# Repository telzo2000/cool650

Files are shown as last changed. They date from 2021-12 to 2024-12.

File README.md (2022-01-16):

# cool650

<br>

# Build Guide
https://github.com/telzo2000/cool650/blob/main/build_guide_for_cool650.md

## What is a cool650?

cool650 is macro pad keyboard,
<br>
and splite keyboard.
<br>
<br>
cool650は、cool635と同じ格子配列のキーボードです。
<br>
cool635は、m.kiが設計した、とてもコンパクトな30％キーボードです。
635とは、開発番号は６で、35キーのキーボードを指しています。
<br>

cool635 SU120で製作した試作版
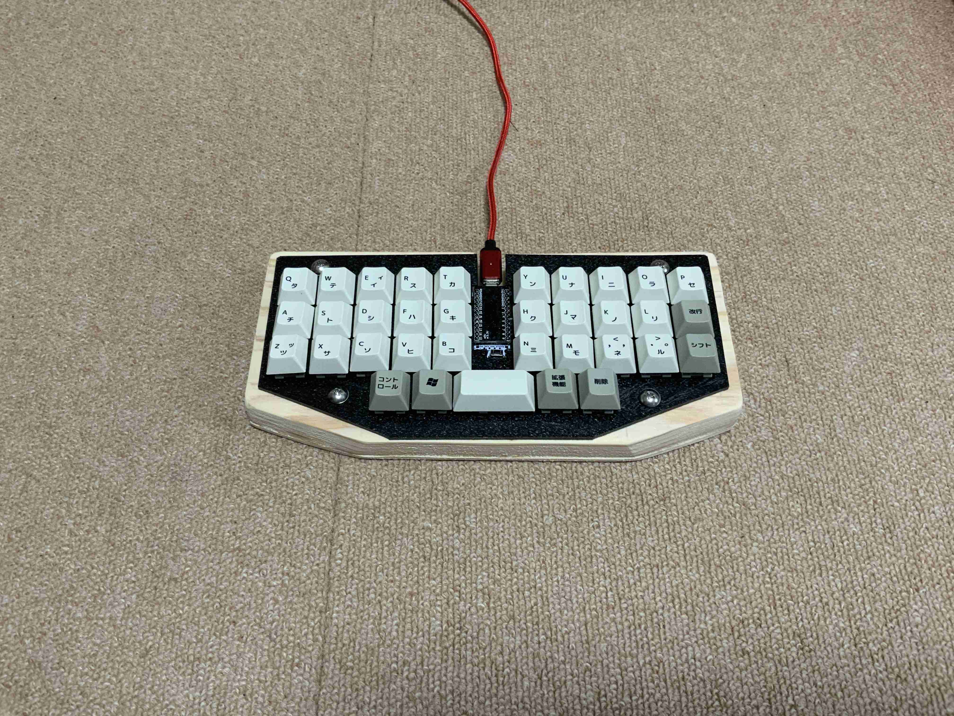
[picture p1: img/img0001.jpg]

分解したcool635
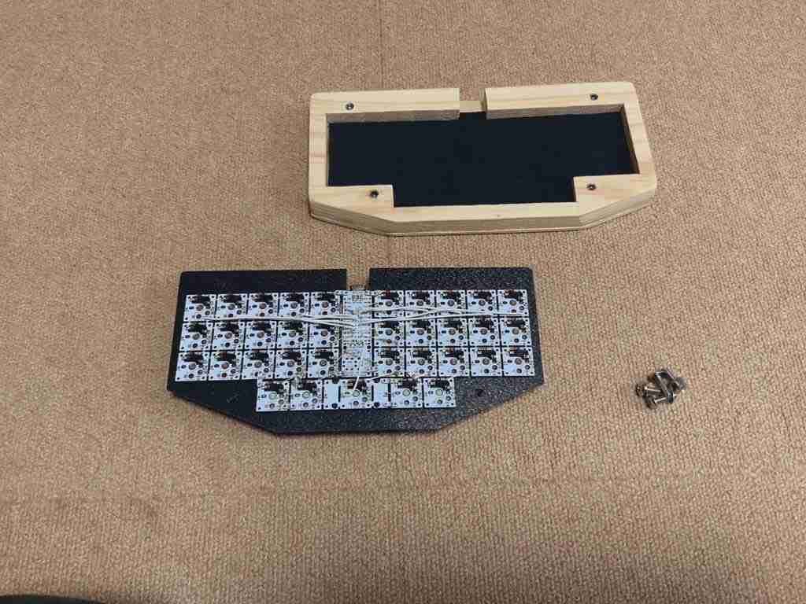
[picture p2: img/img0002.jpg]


cool635 kicadでPCBを設計した完成版
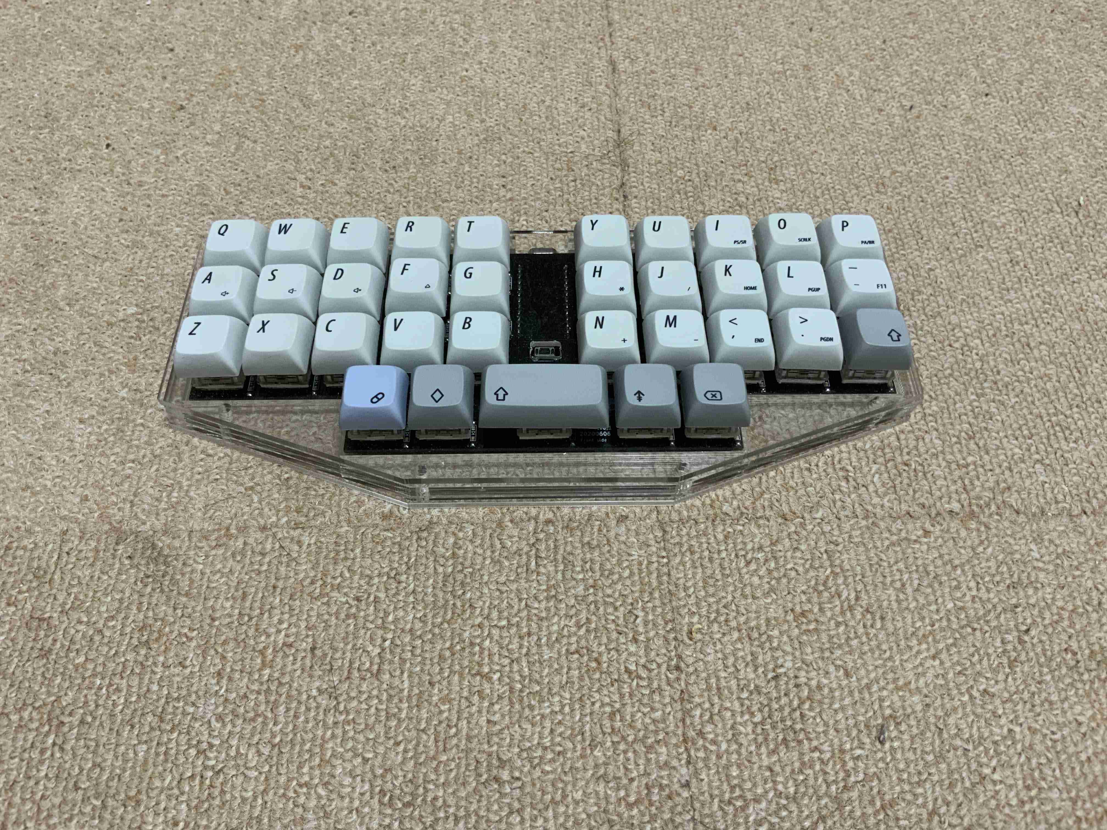
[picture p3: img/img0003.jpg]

裏側から見たcool635
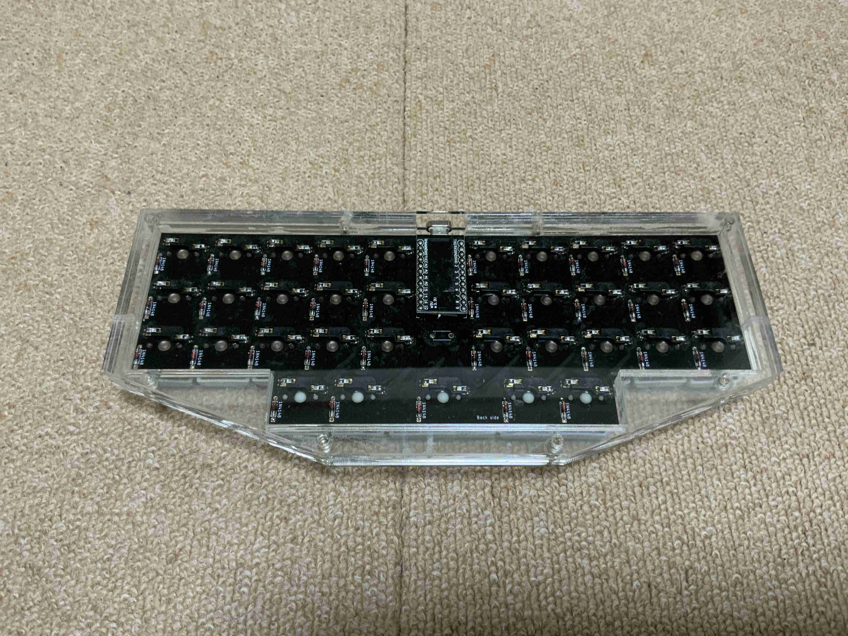
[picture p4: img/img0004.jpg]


cool635の完成版はアクリル積層ケースによって、埃などが侵入しにくいです。
<br>
しかし、m.kiは、ロウスタッガードのキーレイアウトが好みであったため、あまり使うことなく、お蔵入りしました。
<br>
<br>
cool650は、ALLPCBが100mmx150mm以下のPCB製作無料キャンペーンを利用して、設計しました。

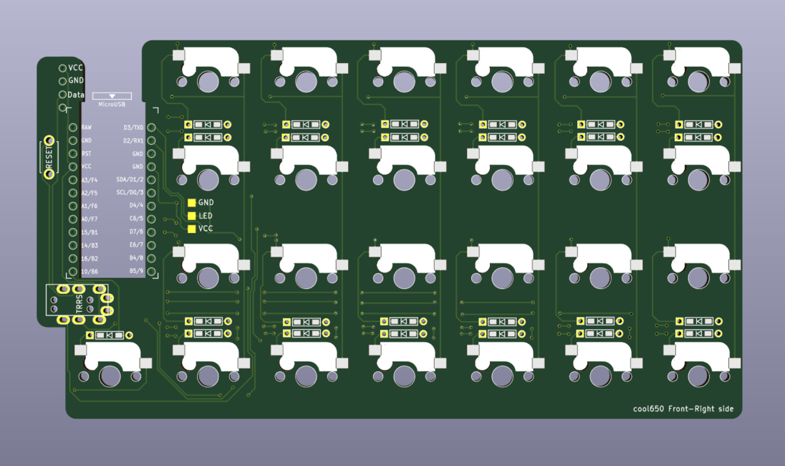
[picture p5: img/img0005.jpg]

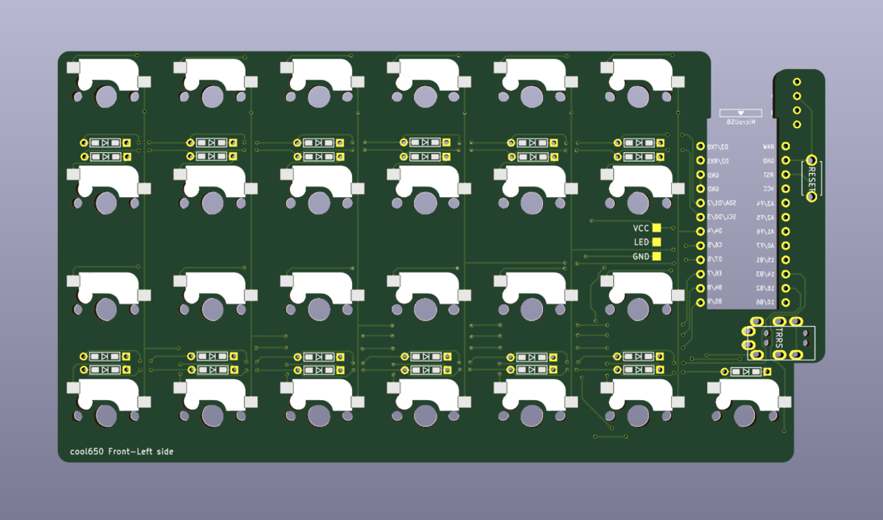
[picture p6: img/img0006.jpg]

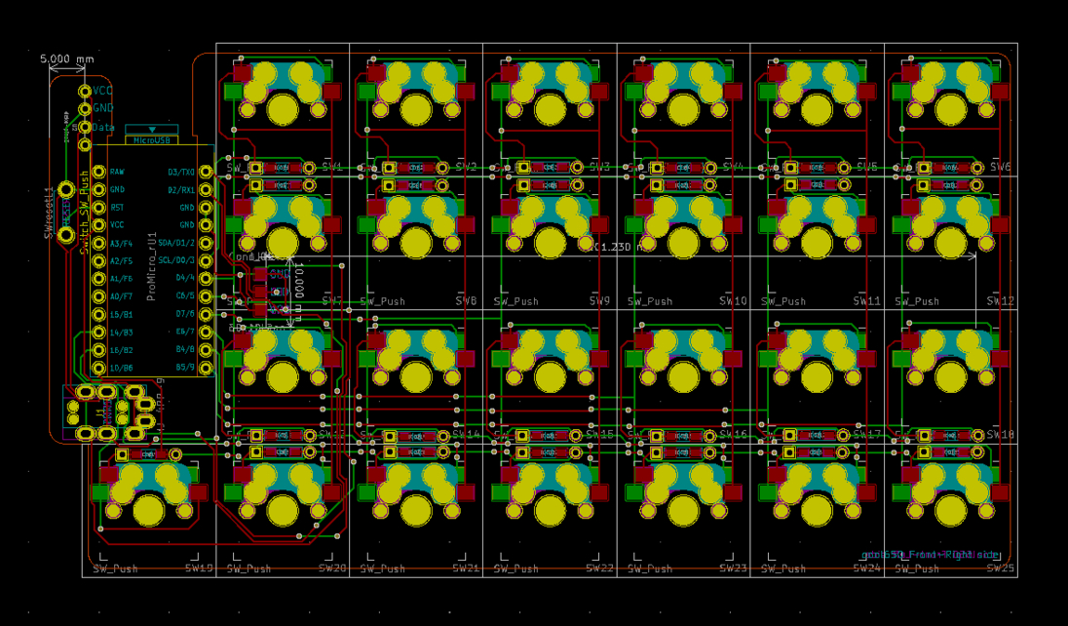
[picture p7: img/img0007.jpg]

ご覧の通り、表裏で使えるようになっています。一つで25キーあり、マクロパッドとして利用できます。二つをTRRSケーブルで繋ぐことにより、格子配列の分割キーボードとしても利用できます。
<br>
ケースはアクリル2mmを使用して、積層したものです。
配線関係の詳細は検討中ですが、60％のPoker互換のキーボードケースには、二つ分が収まります。
汎用ケースに収めることで50キーの格子配列のキーボード、取り出して、分割キーボード、単体で25キーのマクロパッドになることが、cool650のコンセプトです。

二つをケーブルで繋いだcool650

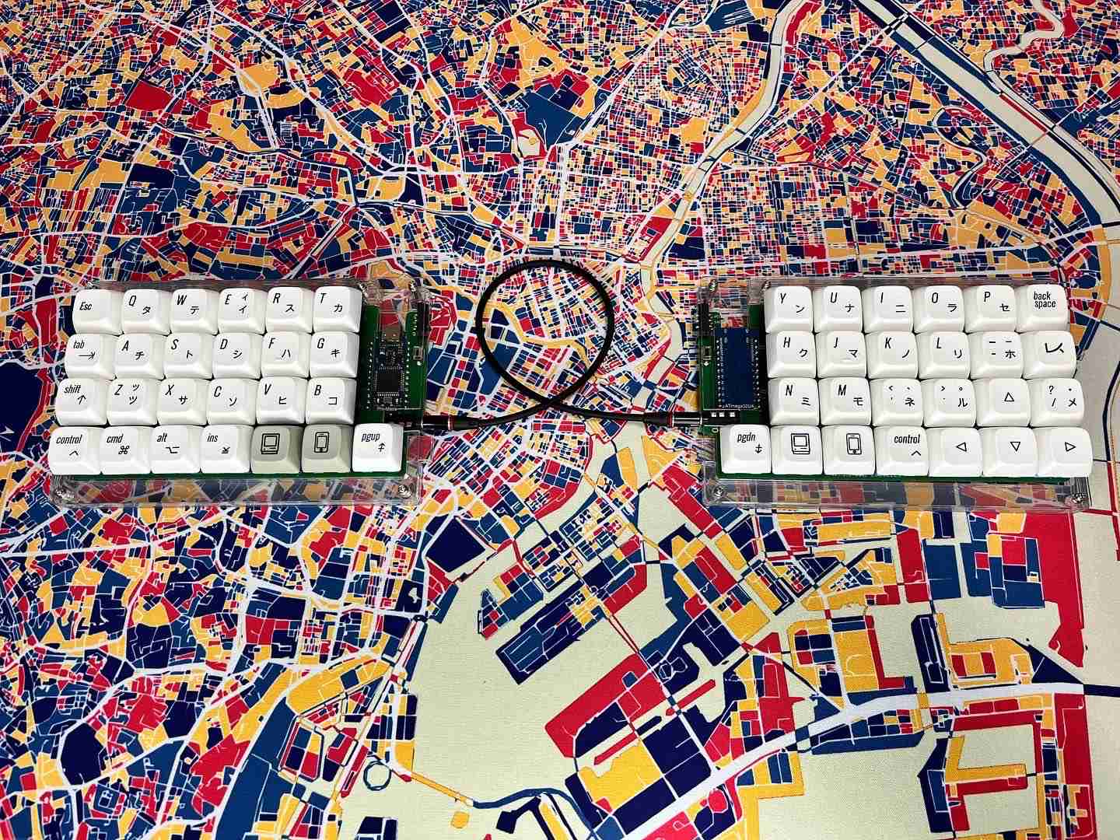
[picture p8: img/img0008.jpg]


60％のPoker互換のキーボードケースに収めたcool650　その１
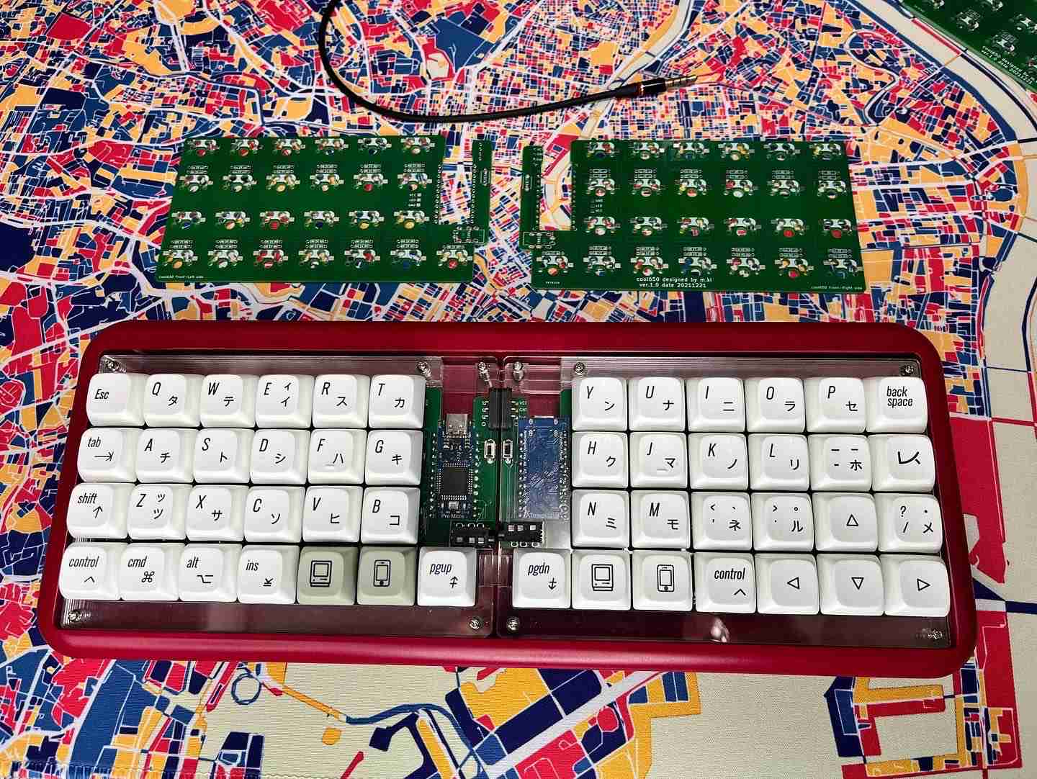
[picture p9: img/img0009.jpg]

60％のPoker互換のキーボードケースに収めたcool650　その２
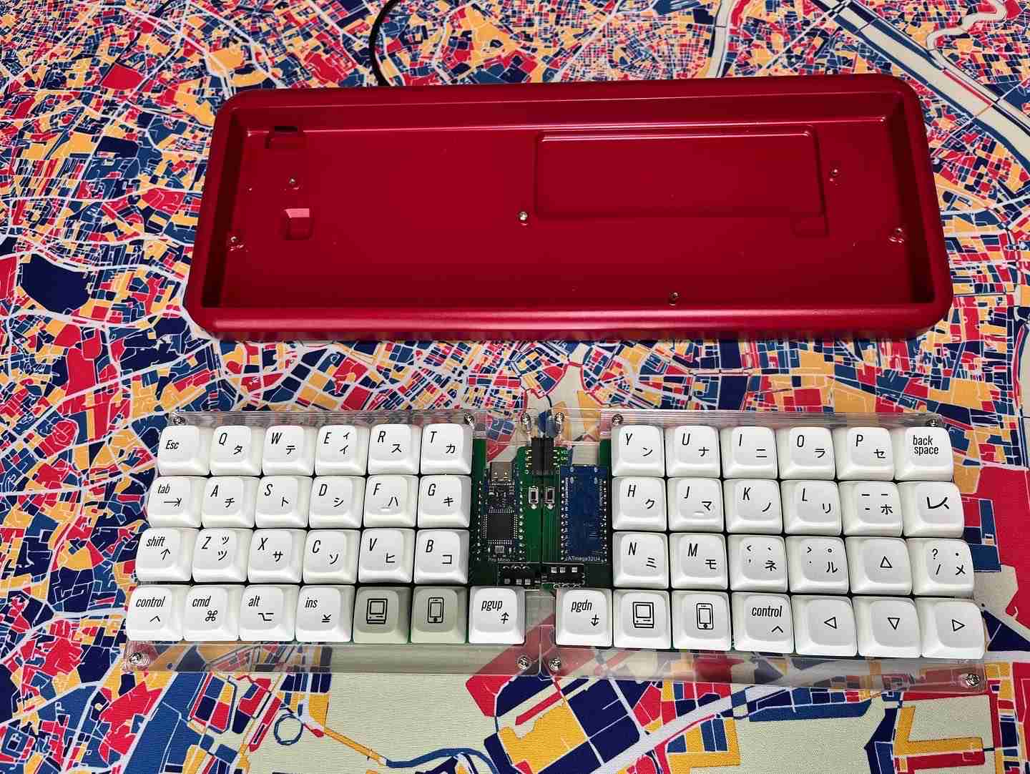
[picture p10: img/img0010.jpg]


最終的には、BBOX60ケースに収納することができました。
<br>
それ以外の60%POKER互換の汎用ケースに収納できる未確認です。
<br>
多分、できません。
<br>

## 令和４年１月６日　追記
<br>
kicad、ガーバー、アクリル積層ケースのデータを追加しました。
将来的には、有償で頒布するつもりですが、自分自身で作成したい方は、このデータをライセンスの範囲内で使用可能です。
<br>
本データを使用して発生した諸問題に対して、m.kiは補償等対応いたしません。
<br>
また、ファームウェアは用意しました。QMK Toolbox等でpro microに書き込んでください。
<br>
Remap等の必要なvia.hexは後日、用意します。
<br>
ファームウェア等の改変する際、下記の画像を参考にしてください。

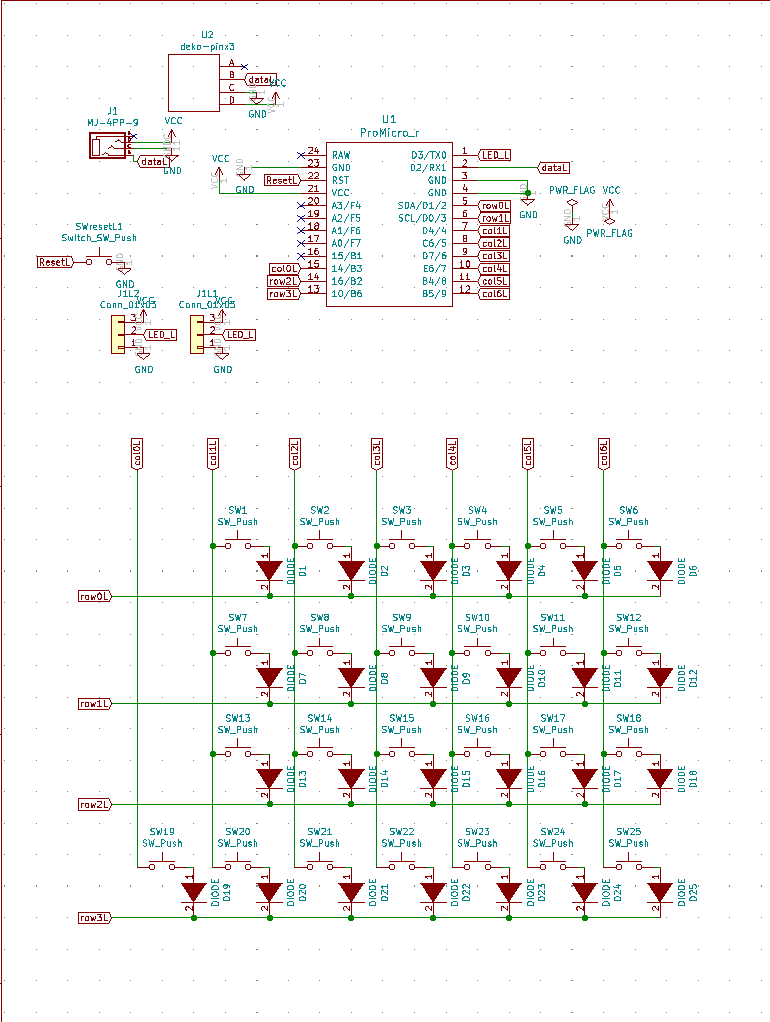
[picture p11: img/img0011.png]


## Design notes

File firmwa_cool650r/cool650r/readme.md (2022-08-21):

# cool650r

cool650r

*A short description of the keyboard/project*

* Keyboard Maintainer: [m.ki](https://github.com/telzo2000)
* Hardware Supported: *The PCBs, controllers supported*
* Hardware Availability: *Links to where you can find this hardware*

Make example for this keyboard (after setting up your build environment):

    make cool650r:default

Flashing example for this keyboard:

    make cool650r:default:flash

See the [build environment setup](https://docs.qmk.fm/#/getting_started_build_tools) and the [make instructions](https://docs.qmk.fm/#/getting_started_make_guide) for more information. Brand new to QMK? Start with our [Complete Newbs Guide](https://docs.qmk.fm/#/newbs).

## Bootloader

Enter the bootloader in 3 ways:

* **Bootmagic reset**: Hold down the key at (0,0) in the matrix (usually the top left key or Escape) and plug in the keyboard
* **Physical reset button**: Briefly press the button on the back of the PCB - some may have pads you must short instead
* **Keycode in layout**: Press the key mapped to `RESET` if it is available

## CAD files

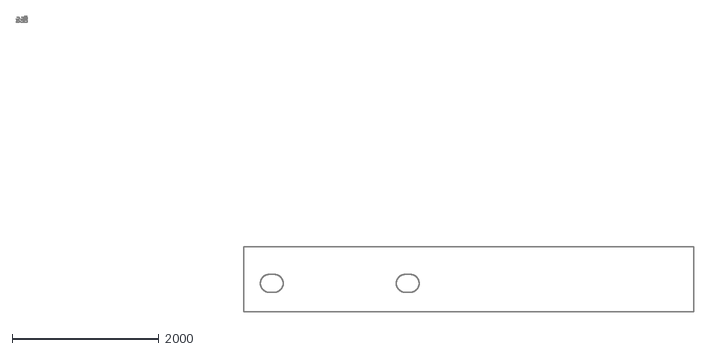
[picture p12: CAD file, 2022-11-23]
casedesign/case_wide/case_wide.dxf
9238.0 x 4030.2

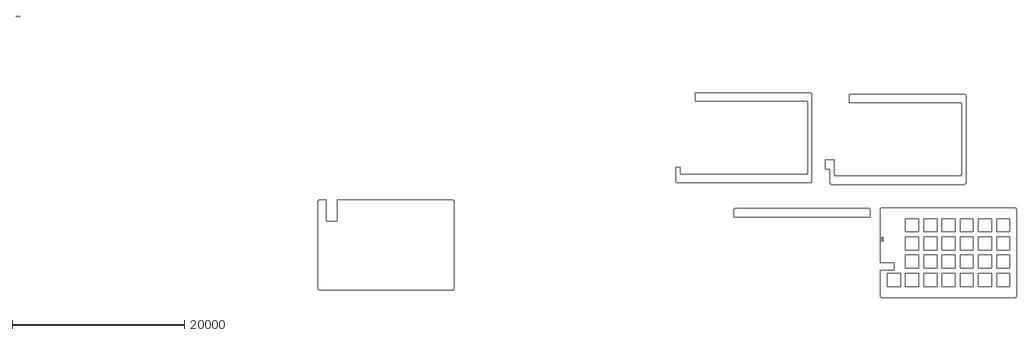
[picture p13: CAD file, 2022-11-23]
casedesign/cool650casedesign_new/cool650case.dxf
116101.8 x 32721.1

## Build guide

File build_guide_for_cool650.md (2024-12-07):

# Build Guide

## Parts list

|番号| 名前 | 数 | 備考 | 調達先の例 | 参考価格（送料込） |
|:-|:-|:-|--|--|--|
|1|PCB|1枚|macro pad|ALLPCB | ALLPCBの無料クーポンで５枚で０円<br>通常だと、26ドル|
||PCB|2枚|splite keyboard|ALLPCB|ALLPCBの無料クーポンで５枚で０円<br>通常だと、26ドル|
|2|M2ネジ|７本|６mm|DIYショップ等|10本程度で100円|
|3|M2ネジ|３本|８mm|DIYショップ等|10本程度で100円|
|4|M2スペーサー|PCB１枚につき５本|８mm|[ヒロスギネット](https://www.hirosugi-net.co.jp/shop/default.aspx)<br>[遊舎工房](https://shop.yushakobo.jp)等|20個で748円（税込）@ヒロスギネット|
|5|pro micro|PCB１枚につき１個|ピンヘッダが必要|[遊舎工房](https://shop.yushakobo.jp)<br>[TALP keyboard](https://talpkeyboard.net)|750円程度|
|6|スイッチプレート|１枚|アクリル|Elecrow|５枚で49.1ドル（送料込み）|
||ミドルプレート|４枚|アクリル|Elecrow|↑同じ|
||ボトムプレート|３枚（大１、小２）|アクリル|Elecrow|↑同じ|
|7|スイッチソケット|pcb１枚につき25個|MX|[遊舎工房](https://shop.yushakobo.jp)<br>[TALP keyboard](https://talpkeyboard.net)|10個で165円（税込）|
|8|ダイオード|pcb１枚につき25個|リードタイプ、SMDのどちらでも可|[遊舎工房](https://shop.yushakobo.jp)<br>[TALP keyboard](https://talpkeyboard.net)|100個で220円（税込）|
|9|リセットスイッチ|PCBにつき１個|タクタイルスイッチとも呼ばれる|[遊舎工房](https://shop.yushakobo.jp)<br>[TALP keyboard](https://talpkeyboard.net)|1個で11円（税込）|
|10|MXスイッチ|PCB１枚につき25個||[遊舎工房](https://shop.yushakobo.jp)<br>[TALP keyboard](https://talpkeyboard.net)等|1個で100円前後|
|11|キーキャップ|PCB１枚につき25個||[遊舎工房](https://shop.yushakobo.jp)<br>[TALP keyboard](https://talpkeyboard.net)|1個で100円前後<br>キーキャップセットで3000円程度から|
|12|ゴム足|PCB１枚につき４個|任意|DIYショップ等|100円程度|
|13|TRRSジャック|２本|splite keyboardとして使用する時|[遊舎工房](https://shop.yushakobo.jp)<br>[TALP keyboard](https://talpkeyboard.net)等|１個55円（税込）|
|14|TRRSケーブル|１本|splite keyboardとして使用する時|[遊舎工房](https://shop.yushakobo.jp)<br>[TALP keyboard](https://talpkeyboard.net)等|300円程度から|
|15|マグネット付きコネクタ|１組|合体して使うのであれば|[Ali Express](https://ja.aliexpress.com/item/1005003150326343.html?spm=a2g0o.9042311.0.0.399f4c4dbOjNiU)|400円程度|
|16|LED|２枚|任意<br>フルカラーシリアルLEDテープ 6個タイプ|[遊舎工房](https://shop.yushakobo.jp/collections/all-keyboard-parts/products/a01sl-00)|１枚550円|
|17|ロータリーエンコーダー|最大２個|任意<br>ver.1.1基板以降、<br>装着可能|[遊舎工房](https://shop.yushakobo.jp)<br>[TALP keyboard](https://talpkeyboard.net)等|400円程度から|

## 作り方

### 1　基板の向きを決める
PCB１枚を使用して、マクロパッドキーボードとして利用する場合は、pro micro設置部分が右側になるか、左側になるか、決定します。
<br>
PCBを２枚使用して、分割キーボードとして利用する場合は、左右それぞれの向きで作成してください。
<br>
<br>

### 2 ダイオードの取り付け
ダイオードをハンダ付けします。
<br>
全体で言えることですが、フラックスを使用してください。失敗を防げます。
<br>
写真ではリードタイプのダイオードのハンダ付けをしています。
<br>
SMDタイプのダイオードも使用できます。
<br>
ダイオードの向きに注意してください。
ダイオードはPCBの下面に取り付けるようにしてください。
<br>
<br>

### 3 スイッチソケットの取り付け
スイッチソケットのハンダ付けをします。
最初にPCBの片側のパッドに、予備ハンダをします。
<br>
次にスイッチソケットを乗せます。
<br>
ハンダゴテで、予備ハンダをした部分を温めて、ハンダ付けをします。
<br>
反対側のパッドとスイッチソケットの間にハンダを流し込むようにハンダ付けをします。
<br>
スイッチソケットの向きに注意してハンダ付けをしてください。
スイッチソケットはPCBの下面に取り付けるようにしてください。
<br>
<br>

### ◯オプション ロータリーエンコーダーの取り付け　
ver.1.1以降の基板では、左右のPCBの一番内側に、キースイッチの代わりに、ロータリーエンコーダーを取り付けることができます。
<br>
その場合、cool650rとなります。
<br>
<br>

### 4 リセットスイッチの取り付け
リセットスイッチ（タクタイルスイッチ）のハンダ付けをします。
リセットスイッチはPCBの上面に取り付けます。
<br>
リセットスイッチをマスキングテープ等で仮固定して、PCBの下面からハンダ付けをします。
<br>
<br>

### 5 TRRSジャックの取り付け
マクロパッドでは、取り付けなくても使用可能です。
<br>
分割キーボードで使用する場合は、左右それぞれぞの基板に１つずつ取り付けます。
<br>
TRRSジャックは、PCBの上面に取り付けます。
<br>
TRRSジャックをマスキングテープ等で仮固定して、PCBの下面からハンダ付けをします。
<br>
<br>

### 6  pro microの取り付け
pro microのハンダ付けをします。
本キーボードでは、薄さを求めるために、pro microをピンヘッダを使わずに、基板に直付けします。
<br>
ここでは、pro microのUSB端子や部品が付いている表面とします。
<br>
pro microの表面がPCB側に向くよう取り付けます。
pro microのUSB端子や部品がPCBに干渉しないよう、PCBの一部が切り抜かれています。
<br>
pro microの設置向きは、pro microの「RAW」の印字がPCBの外側にしてください。
<br>
<br>
＜ブレッドボードがある場合＞
<br>
取り付け方は次の手順になります。
<br>
①ブレッドボードにピンヘッダを挿して、pro microの表面をブレッドボード側に向けて、ピンヘッダを通します。
<br>
②pro microの裏面からハンダ付けをして、ピンヘッダを固定します。
<br>
③ブレッドボードからpro microを抜きます。
<br>
④ピンヘッダに付いているプラスチックをラジオペンチ等を用いて、外します。
<br>
⑤pro microの表面がPCB側に向くように、挿します。マスキングテープ等で仮固定します。
<br>
⑥pro microを挿したPCBの反対側からハンダ付けをします。長すぎるピンはニッパー等で切ってください。
<br>
<br>
＜ブレッドボードがない場合＞
<br>
取り付け方は次の手順になります。
<br>
①ピンヘッダをpro microの裏面から、pro micro、PCBの順で挿します。
マスキングテープで仮固定します。
<br>
②PCB側からピンヘッダをハンダ付けします。
<br>
③pro micro裏面のピンヘッダのプラスチックをラジオペンチ等を用いて、外します。
<br>
④pro microの裏面のハンダ付けをします。長すぎるピンはニッパー等で切ってください。
<br>
<br>

## 7 マグネット付きコネクタの取り付け
マクロパッドでは、取り付けなくても使用可能です。
<br>
分割キーボードで使用する場合は、左右それぞれぞの基板に１つずつ取り付けます。
<br>
マグネット付きコネクタがなくても、TRRSジャック、ケーブルがあれば、分割キーボードとして動作します。
<br>
マグネット付きコネクタがあると、繋げて一体型キーボードとして利用できます。
マグネット付きコネクタは、３ピンでも４ピンでも使用可能です。
<br>
３ピンの場合は、PCBの奥側から３つのピンホールを使用してください。
<br>
マグネット付きコネクタはPCB上面からピンを挿して、マスキングテープ等で仮固定してください。
下面からハンダ付けをしてください。
<br>
https://twitter.com/0002ozlet/status/1488121245031751683
<br>
<br>

## 8 LEDの装着（任意）
cool650はフルカラーシリアルLEDテープを、PCB下面に装着することができます。
<br>
PCB下面を表側にしておきます。
LEDテープに記載されたGND等の文字に注意して、テープの裏紙を剥がして貼ります。
<br>
次にハンダで多めにもって、PCBの端子とLEDテープの端子にブリッジして接続します。
<br>
https://twitter.com/0002ozlet/status/1502969631702626304
<br>
<br>

## 9 ファームウェア
cool650は一つでマクロパッドとして、二つで分割キーボード（または一体型キーボード）として設計されました。
そのため、複数のファームウェアが必要となります。
<br>
ただ、分割キーボード用のファームウェアをマクロパッドとしてのcool650に入れても、問題なく動作します。
<br>
ここで、ファームウェアを入れて、動作するか確認してください。キーが反応しない時は、テスターで導通を確認して、ハンダ付けをしなおしてください。テスターがない場合は、最初にpro microのピンと、PCB側のピンをハンダゴテでハンダを温め直してください。
改善が見られない時は、反応しないキーのダイオードの向きが間違っていないか確認して、間違っていた時は修正ください。
<br>
この後に組み立てになりますと、ハンダの修正等が面倒になりますので、この時点で、導通の確認を必ずしてください。
<br>
REMAPに登録されていまので、次のサイトにアクセスすれば、ファームウェアの導入もスムーズにできます。
<br>
[cool650の場合](https://remap-keys.app/catalog/ch6fui4FoHOMFDozhaye/firmware)
<br>

[ロータリーエンコーダー付きのcool650の場合（cool650r）](https://remap-keys.app/catalog/PqnhgvFviyU6LFA36Hg6/firmware)
<br>

片手のみで、右手用マクロパッドとして利用する場合は、こちらのファームウェアを利用してください。<br>
[右手用マクロパッドの場合（cool650half）](https://remap-keys.app/catalog/DK1eRhQSgAZz2aAV9A0r/firmware)

参考<br>

https://github.com/telzo2000/Hello_keyboard/blob/main/readme_about_firmware.md

## 10 組み立て
スイッチプレートの向きに注意して、５箇所にM2ネジ６mmを上面から挿しこみ、反対側からM2スペーサー８mmで固定してください。
<br>
次に、スイッチプレートの上面からキースイッチを挿しこみ、反対側からPCBのスイッチソケットで受けてください。
その際、キースッチの足が真っ直ぐ、キーソケットに入らないと導通が不十分となり、打鍵しても入力されない不具合を起こします。
<br>
２mm厚のスイッチプレートでは、キースイッチをしっかりと引っかかることができません。
気にせず、どんどんキースイッチをスイッチプレートに挿し、その向こう側にあるPCBのキーソケットに挿しこみましょう。
<br>
<br>
キースイッチが下に向くように置きましょう。M2スペーサーがミドルプレートの穴に通るように、ミドルプレートを積み重ねていきます。
その際、分割キーボードで使う場合はミドルプレートの形状をよく見て、互い違いになるように積み重ねてください。
マクロパッドで使い場合は、ミドルプレートの積み重ね方は自由です。もし、凸部が気になるのであれば、切除してもよいでしょう。
<br>
最後に、ボトムプレート（大１）を乗せてください。２箇所をM2ネジ６mmで締めてください。
また、ボトムプレート（小２）を重ねて乗せ、M2ネジ８mmで締めてください。
<br>
これで完成です。
<br>
<br>
任意で、クッションゴム等をつければ、滑りにくくなります。
<br>

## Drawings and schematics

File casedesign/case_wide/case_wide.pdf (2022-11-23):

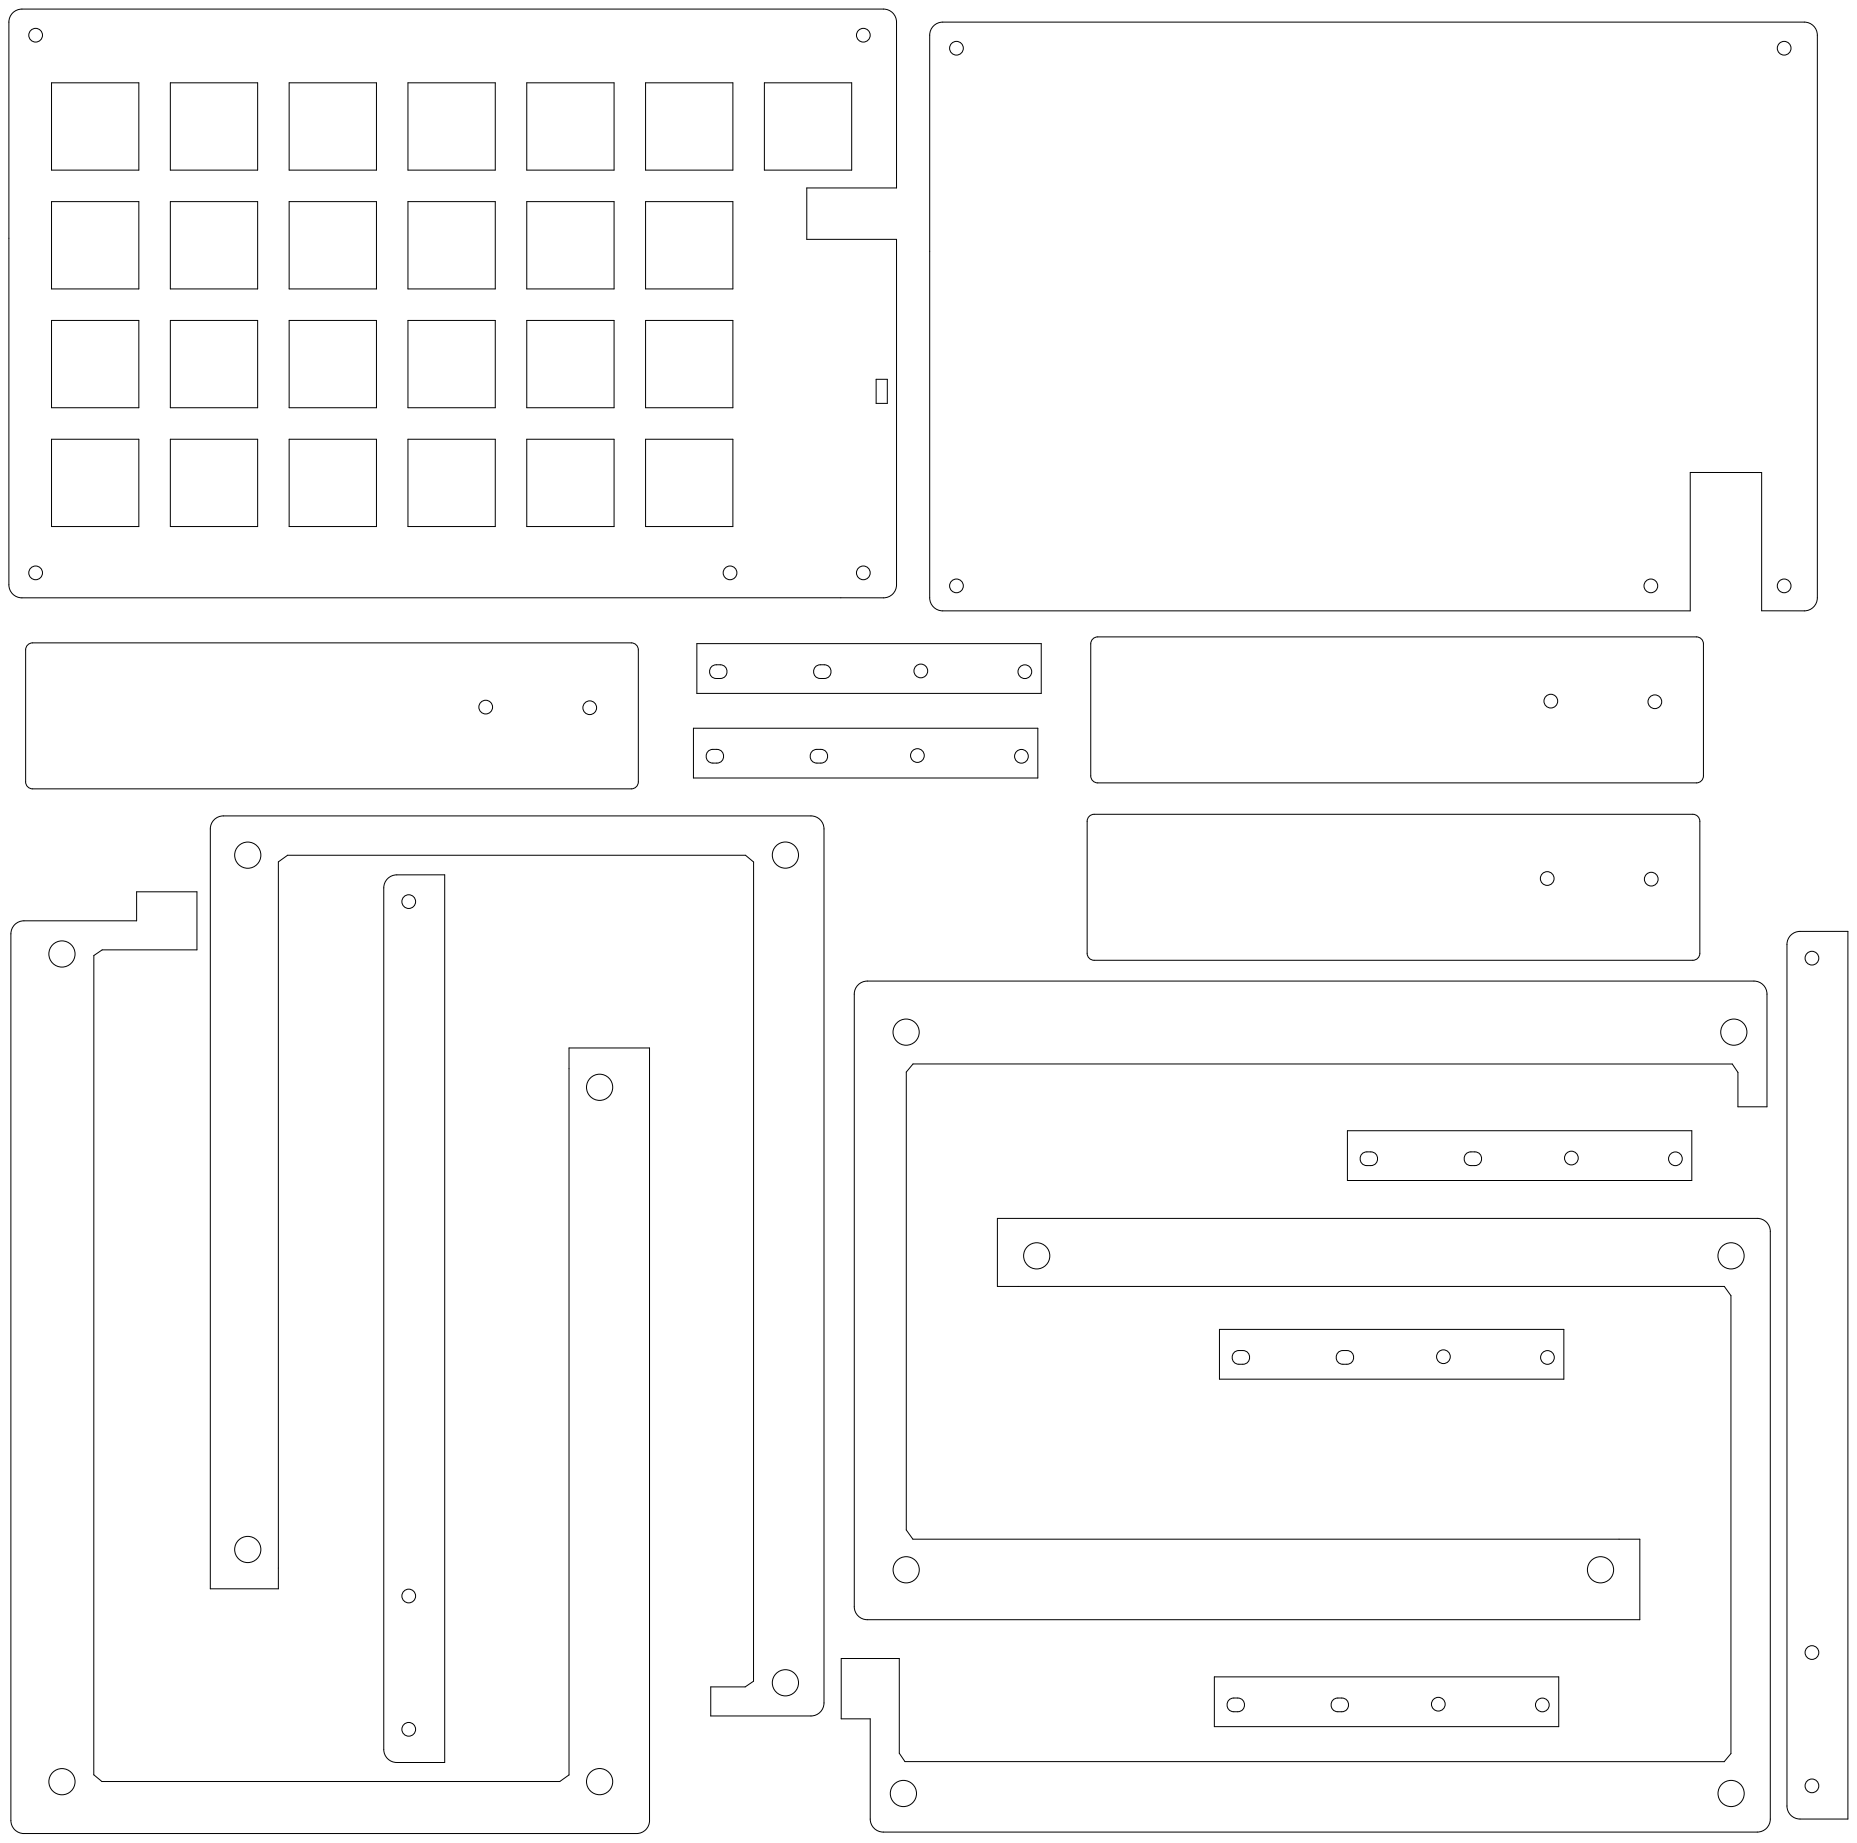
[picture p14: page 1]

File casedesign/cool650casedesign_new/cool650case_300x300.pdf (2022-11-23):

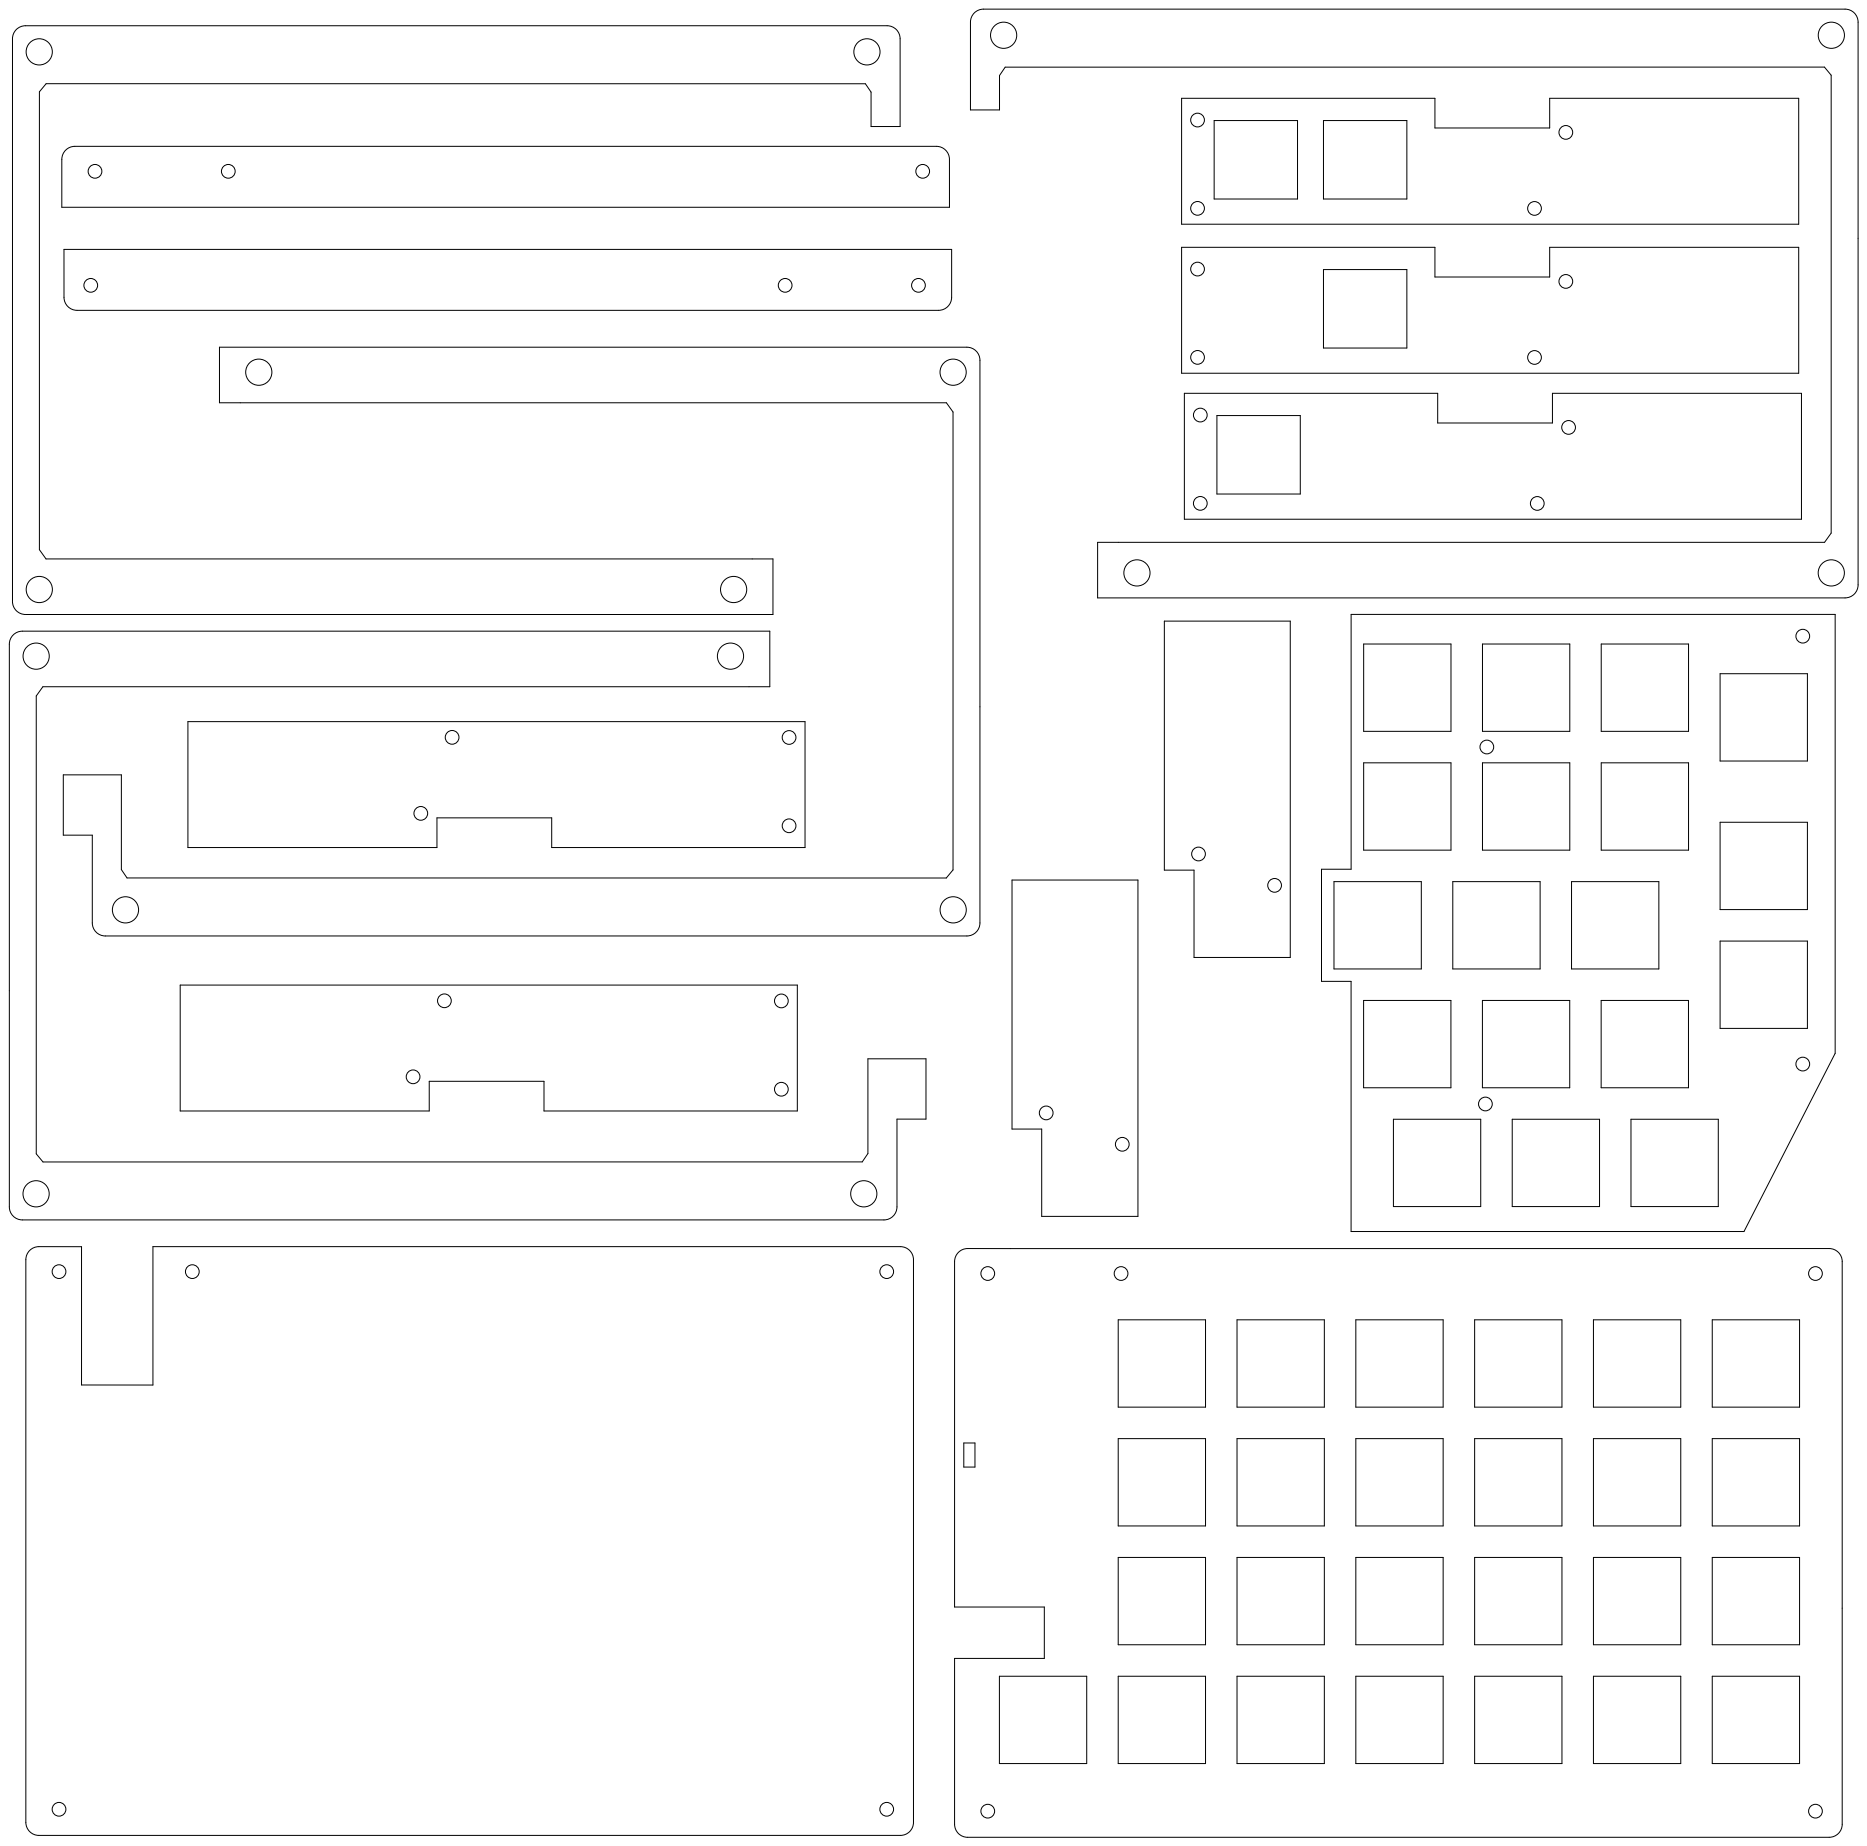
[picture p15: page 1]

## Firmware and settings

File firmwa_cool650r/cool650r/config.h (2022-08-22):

// Copyright 2022 m.ki (@telzo2000)
// SPDX-License-Identifier: GPL-2.0-or-later

#pragma once

#include "config_common.h"

/* USB Device descriptor parameter */
#define VENDOR_ID    0x4D43
#define PRODUCT_ID   0x0651
#define DEVICE_VER   0x0001
#define MANUFACTURER telzo2000
#define PRODUCT      cool650r

/* key matrix size */
#define MATRIX_ROWS 10
#define MATRIX_COLS 7

/*
 * Keyboard Matrix Assignments
 *
 * Change this to how you wired your keyboard
 * COLS: AVR pins used for columns, left to right
 * ROWS: AVR pins used for rows, top to bottom
 * DIODE_DIRECTION: COL2ROW = COL = Anode (+), ROW = Cathode (-, marked on diode)
 *                  ROW2COL = ROW = Anode (+), COL = Cathode (-, marked on diode)
 *
 */
#define MATRIX_ROW_PINS { D1, D0, B2 , B6,  D3 }
#define MATRIX_COL_PINS { B3, D4, C6, D7, E6, B4, B5 }
#define MATRIX_ROW_PINS_RIGHT { D1, D0, B2 , B6, D3 }
#define MATRIX_COL_PINS_RIGHT { B3, D4, C6, D7, E6, B4, B5 }
#define UNUSED_PINS

/* COL2ROW, ROW2COL */
#define DIODE_DIRECTION ROW2COL

#define ENCODERS_PAD_A { F7 }
#define ENCODERS_PAD_B { B1 }



/*
 * Split Keyboard specific options, make sure you have 'SPLIT_KEYBOARD = yes' in your rules.mk, and define SOFT_SERIAL_PIN.
 */
#define SOFT_SERIAL_PIN D2  // or D1, D2, D3, E6

//#define LED_NUM_LOCK_PIN B0
//#define LED_CAPS_LOCK_PIN B1
//#define LED_SCROLL_LOCK_PIN B2
//#define LED_COMPOSE_PIN B3
//#define LED_KANA_PIN B4

//#define BACKLIGHT_PIN B7
//#define BACKLIGHT_LEVELS 3
//#define BACKLIGHT_BREATHING

#define RGB_DI_PIN D3
#ifdef RGB_DI_PIN
#    define RGBLED_NUM 16
#    define RGBLIGHT_HUE_STEP 8
#    define RGBLIGHT_SAT_STEP 8
#    define RGBLIGHT_VAL_STEP 8
#    define RGBLIGHT_LIMIT_VAL 255 /* The maximum brightness level */
#    define RGBLIGHT_SLEEP  /* If defined, the RGB lighting will be switched off when the host goes to sleep */
/*== all animations enable ==*/
#    define RGBLIGHT_ANIMATIONS
/*== or choose animations ==*/
#    define RGBLIGHT_EFFECT_BREATHING
#    define RGBLIGHT_EFFECT_RAINBOW_MOOD
#    define RGBLIGHT_EFFECT_RAINBOW_SWIRL
#    define RGBLIGHT_EFFECT_SNAKE
#    define RGBLIGHT_EFFECT_KNIGHT
#    define RGBLIGHT_EFFECT_CHRISTMAS
#    define RGBLIGHT_EFFECT_STATIC_GRADIENT
#    define RGBLIGHT_EFFECT_RGB_TEST
#    define RGBLIGHT_EFFECT_ALTERNATING
/*== customize breathing effect ==*/
/*==== (DEFAULT) use fixed table instead of exp() and sin() ====*/
#    define RGBLIGHT_BREATHE_TABLE_SIZE 256      // 256(default) or 128 or 64
/*==== use exp() and sin() ====*/
#    define RGBLIGHT_EFFECT_BREATHE_CENTER 1.85  // 1 to 2.7
#    define RGBLIGHT_EFFECT_BREATHE_MAX    255   // 0 to 255
#endif
/* Debounce reduces chatter (unintended double-presses) - set 0 if debouncing is not needed */
#define DEBOUNCE 5

/* define if matrix has ghost (lacks anti-ghosting diodes) */
//#define MATRIX_HAS_GHOST

/* Mechanical locking support. Use KC_LCAP, KC_LNUM or KC_LSCR instead in keymap */
#define LOCKING_SUPPORT_ENABLE
/* Locking resynchronize hack */
#define LOCKING_RESYNC_ENABLE

/* If defined, GRAVE_ESC will always act as ESC when CTRL is held.
 * This is useful for the Windows task manager shortcut (ctrl+shift+esc).
 */
//#define GRAVE_ESC_CTRL_OVERRIDE

/*
 * Force NKRO
 *
 * Force NKRO (nKey Rollover) to be enabled by default, regardless of the saved
 * state in the bootmagic EEPROM settings. (Note that NKRO must be enabled in the
 * makefile for this to work.)
 *
 * If forced on, NKRO can be disabled via magic key (default = LShift+RShift+N)
 * until the next keyboard reset.
 *
 * NKRO may prevent your keystrokes from being detected in the BIOS, but it is
 * fully operational during normal computer usage.
 *
 * For a less heavy-handed approach, enable NKRO via magic key (LShift+RShift+N)
 * or via bootmagic (hold SPACE+N while plugging in the keyboard). Once set by
 * bootmagic, NKRO mode will always be enabled until it is toggled again during a
 * power-up.
 *
 */
//#define FORCE_NKRO

/*
 * Feature disable options
 *  These options are also useful to firmware size reduction.
 */

/* disable debug print */
//#define NO_DEBUG

/* disable print */
//#define NO_PRINT

/* disable action features */
//#define NO_ACTION_LAYER
//#define NO_ACTION_TAPPING
//#define NO_ACTION_ONESHOT

/* disable these deprecated features by default */
#define NO_ACTION_MACRO
#define NO_ACTION_FUNCTION

/* Bootmagic Lite key configuration */
//#define BOOTMAGIC_LITE_ROW 0
//#define BOOTMAGIC_LITE_COLUMN 0

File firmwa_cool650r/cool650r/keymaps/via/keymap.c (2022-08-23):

// Copyright 2021 m.ki (@telzo2000)
// SPDX-License-Identifier: GPL-2.0-or-later

#include QMK_KEYBOARD_H

// Defines names for use in layer keycodes and the keymap
enum layer_names {
    _QWERTY,
    _LOWER,
    _RAISE,
    _ADJUST,
};

// Defines the keycodes used by our macros in process_record_user
enum custom_keycodes {
    QWERTY = SAFE_RANGE,
    LOWER,
    RAISE,
    ADJUST,
};
const uint16_t PROGMEM keymaps[][MATRIX_ROWS][MATRIX_COLS] = {
    
    [_QWERTY] = LAYOUT(
    KC_ESC,  KC_Q,    KC_W,    KC_E,    KC_R,    KC_T,    KC_Y,    KC_U,    KC_I,    KC_O,    KC_P,    KC_BSPC,
    KC_TAB,  KC_A,    KC_S,    KC_D,    KC_F,    KC_G,    KC_H,    KC_J,    KC_K,    KC_L,    KC_MINUS,    KC_ENT,
    KC_INSERT, KC_Z,    KC_X,    KC_C,    KC_V,    KC_B,    KC_N,    KC_M,    KC_COMM,   KC_DOT,  KC_UP,  KC_SLSH, 
    KC_LSFT, KC_LCTL, KC_LALT, KC_LGUI, KC_SPACE,LT(_LOWER,KC_SPACE),C(KC_SPACE),G(KC_SPACE),LT(_RAISE,KC_SPACE),KC_SPACE, KC_RCTL,KC_LEFT, KC_DOWN, KC_RIGHT,
    KC_PPLS,KC_PMNS,KC_WH_U,KC_WH_D
  ),
  
  [_LOWER] = LAYOUT(
    KC_TAB,  KC_1,    KC_2,    KC_3,    KC_4,    KC_5,    KC_6,    KC_7,    KC_8,    KC_9,    KC_0,    KC_BSPC,
    KC_LCTL,  KC_EXLM, KC_AT,   KC_HASH, KC_DLR,  KC_PERC, KC_CIRC, KC_AMPR, KC_ASTR, KC_LPRN, KC_RPRN, KC_ENT,
    KC_NO, KC_PPLS,    KC_PMNS,    KC_PAST,    KC_PSLS,    KC_PEQL,    KC_GRV,    KC_JYEN,    RSFT(KC_LBRC),   RSFT(KC_RBRC),  RSFT(KC_MINS), KC_RSFT,
  KC_LSFT, KC_LCTL, KC_LALT, KC_LGUI, KC_SPACE,LT(_LOWER,KC_SPACE),C(KC_SPACE),G(KC_SPACE),LT(_RAISE,KC_SPACE),KC_SPACE, KC_RCTL,KC_LEFT, KC_DOWN, KC_RIGHT,
    KC_PPLS,KC_PMNS,KC_WH_U,KC_WH_D
  ) ,
 
  
  [_RAISE] = LAYOUT(
    KC_TAB,  KC_F1,    KC_F2,    KC_F3,    KC_F4,    KC_F5,    KC_F6,    KC_F7,    KC_F8,    KC_F9,    KC_F10,    KC_DEL,
    KC_LCTL,  KC_AT,    KC_BSLS,    KC_SCLN,   RSFT(KC_SCLN), KC_QUOT,    KC_LEFT, KC_DOWN, KC_UP, KC_RIGHT, KC_EQL, KC_ENT,
    KC_NO, RGB_TOG,    RGB_MOD,    RGB_HUI,    RGB_HUD,    RGB_SAI,    RGB_SAD,    RGB_VAI,    KC_LBRC,   KC_RBRC,  KC_BSLASH, KC_RSFT,
KC_LSFT, KC_LCTL, KC_LALT, KC_LGUI, KC_SPACE,LT(_LOWER,KC_SPACE),C(KC_SPACE),G(KC_SPACE),LT(_RAISE,KC_SPACE),KC_SPACE, KC_RCTL,KC_LEFT, KC_DOWN, KC_RIGHT,
    KC_PPLS,KC_PMNS,KC_WH_U,KC_WH_D
  ) 
};

keyevent_t encoder1_ccw = {
    .key = (keypos_t){.row = 4, .col = 0},
    .pressed = false
};

keyevent_t encoder1_cw = {
    .key = (keypos_t){.row = 4, .col = 1},
    .pressed = false
};

keyevent_t encoder2_ccw = {
    .key = (keypos_t){.row = 9, .col = 0},
    .pressed = false
};

keyevent_t encoder2_cw = {
    .key = (keypos_t){.row = 9, .col = 1},
    .pressed = false
};


void matrix_scan_user(void) {
    if (IS_PRESSED(encoder1_ccw)) {
        encoder1_ccw.pressed = false;
        encoder1_ccw.time = (timer_read() | 1);
        action_exec(encoder1_ccw);
    }

    if (IS_PRESSED(encoder1_cw)) {
        encoder1_cw.pressed = false;
        encoder1_cw.time = (timer_read() | 1);
        action_exec(encoder1_cw);
    }

    if (IS_PRESSED(encoder2_ccw)) {
        encoder2_ccw.pressed = false;
        encoder2_ccw.time = (timer_read() | 1);
        action_exec(encoder2_ccw);
    }

    if (IS_PRESSED(encoder2_cw)) {
        encoder2_cw.pressed = false;
        encoder2_cw.time = (timer_read() | 1);
        action_exec(encoder2_cw);
    }
}

bool encoder_update_user(uint8_t index, bool clockwise) {
    if (index == 0) {
        if (clockwise) {
            encoder1_cw.pressed = true;
            encoder1_cw.time = (timer_read() | 1);
            action_exec(encoder1_cw);
        } else {
            encoder1_ccw.pressed = true;
            encoder1_ccw.time = (timer_read() | 1);
            action_exec(encoder1_ccw);
        }
    } else if (index == 1) {
        if (clockwise) {
            encoder2_cw.pressed = true;
            encoder2_cw.time = (timer_read() | 1);
            action_exec(encoder2_cw);
        } else {
            encoder2_ccw.pressed = true;
            encoder2_ccw.time = (timer_read() | 1);
            action_exec(encoder2_ccw);
        }
 
    }

    return true;
}
